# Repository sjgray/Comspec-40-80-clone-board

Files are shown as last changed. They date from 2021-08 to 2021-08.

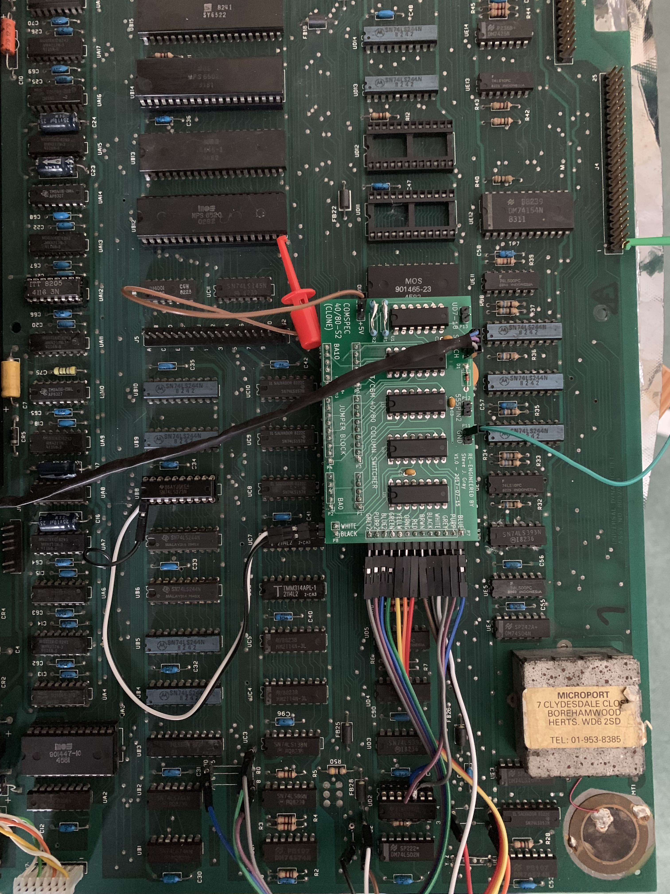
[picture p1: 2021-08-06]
pics/IMG_3752.jpg

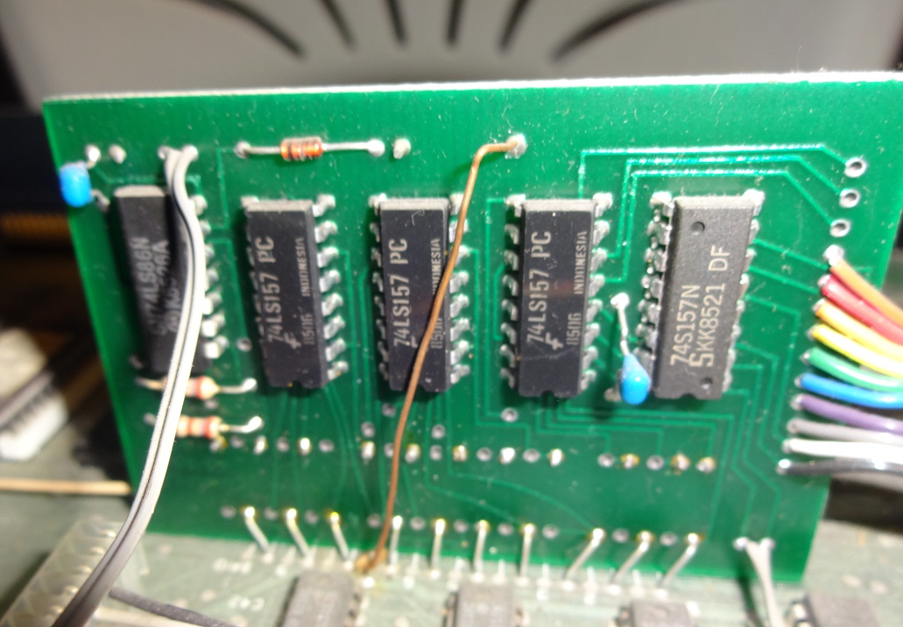
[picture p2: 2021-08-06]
pics/Comspec4080s2.jpg

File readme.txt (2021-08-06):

Comspec 40/80-S2 board Clone
============================

This is a clone of the Comspec 40/80 S2 board for PET/CBM computers.
This board allows the PET to switch between real 40 or 80 column video modes.
Whe the board is switched the computer is reset. These boards were supplied
with both 40 and 80 column Editor ROMs combined into a single EPROM. A wire
from the Comspec board to the upper address pin of the EPROM automatically
selected the correct ROM for the selected video mode.

More information can be found on the web:
http://www.6502.org/users/sjgray/projects/cbm4080/index.html

Steve

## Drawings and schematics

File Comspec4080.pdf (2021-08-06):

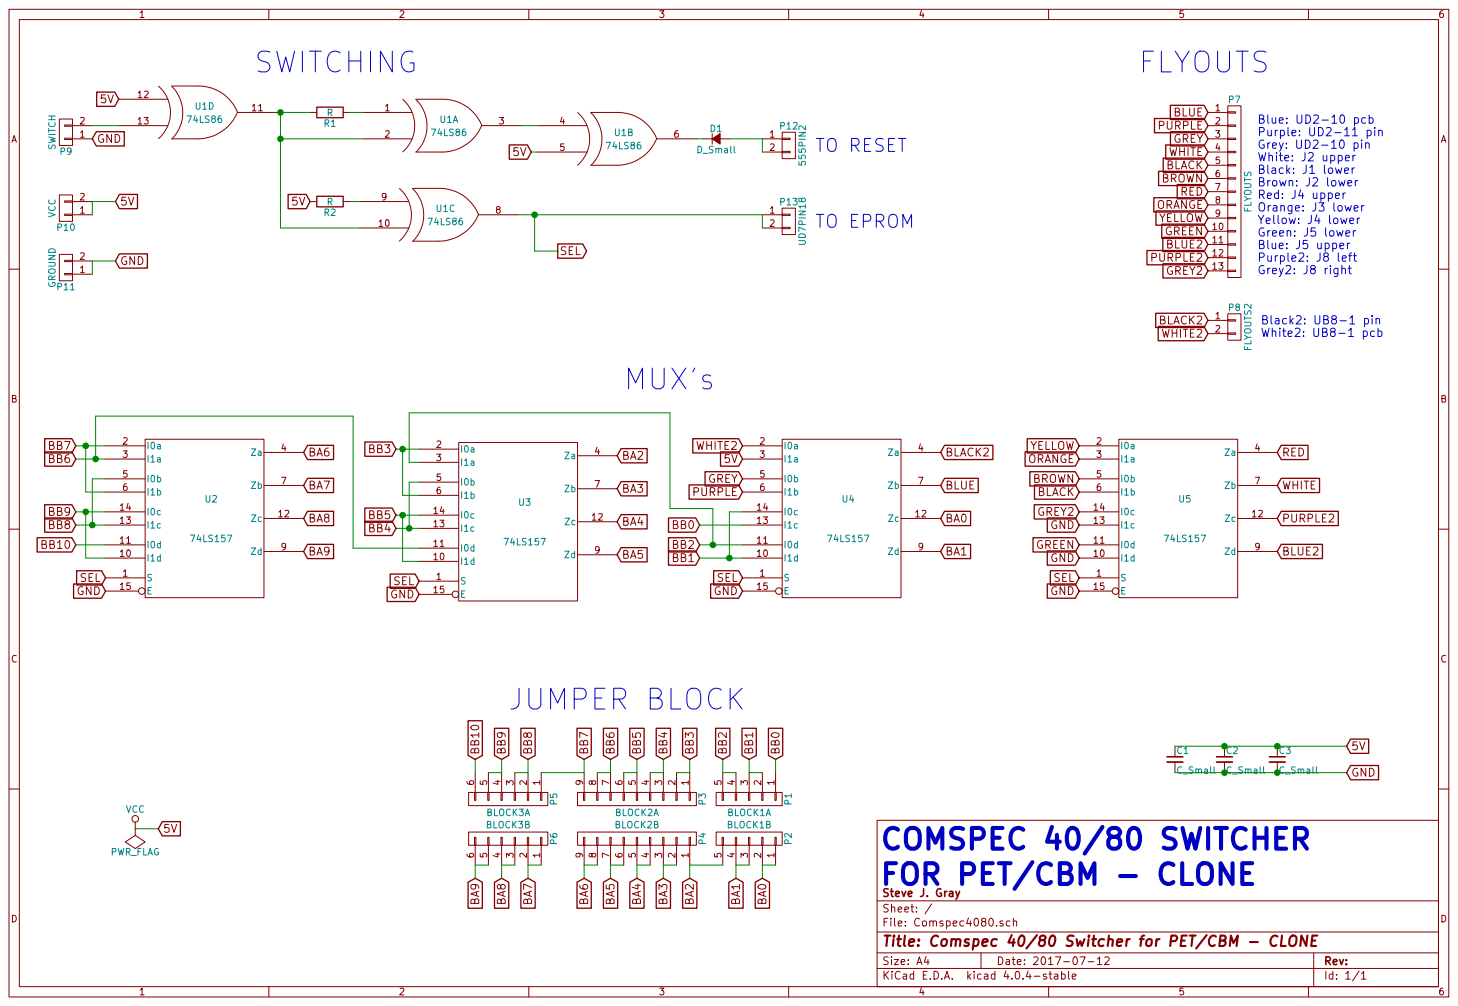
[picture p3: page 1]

FOR PET/CBM - CLONE

Id: 1/1 Title: Comspec 40/80 Switcher for PET/CBM - CLONE

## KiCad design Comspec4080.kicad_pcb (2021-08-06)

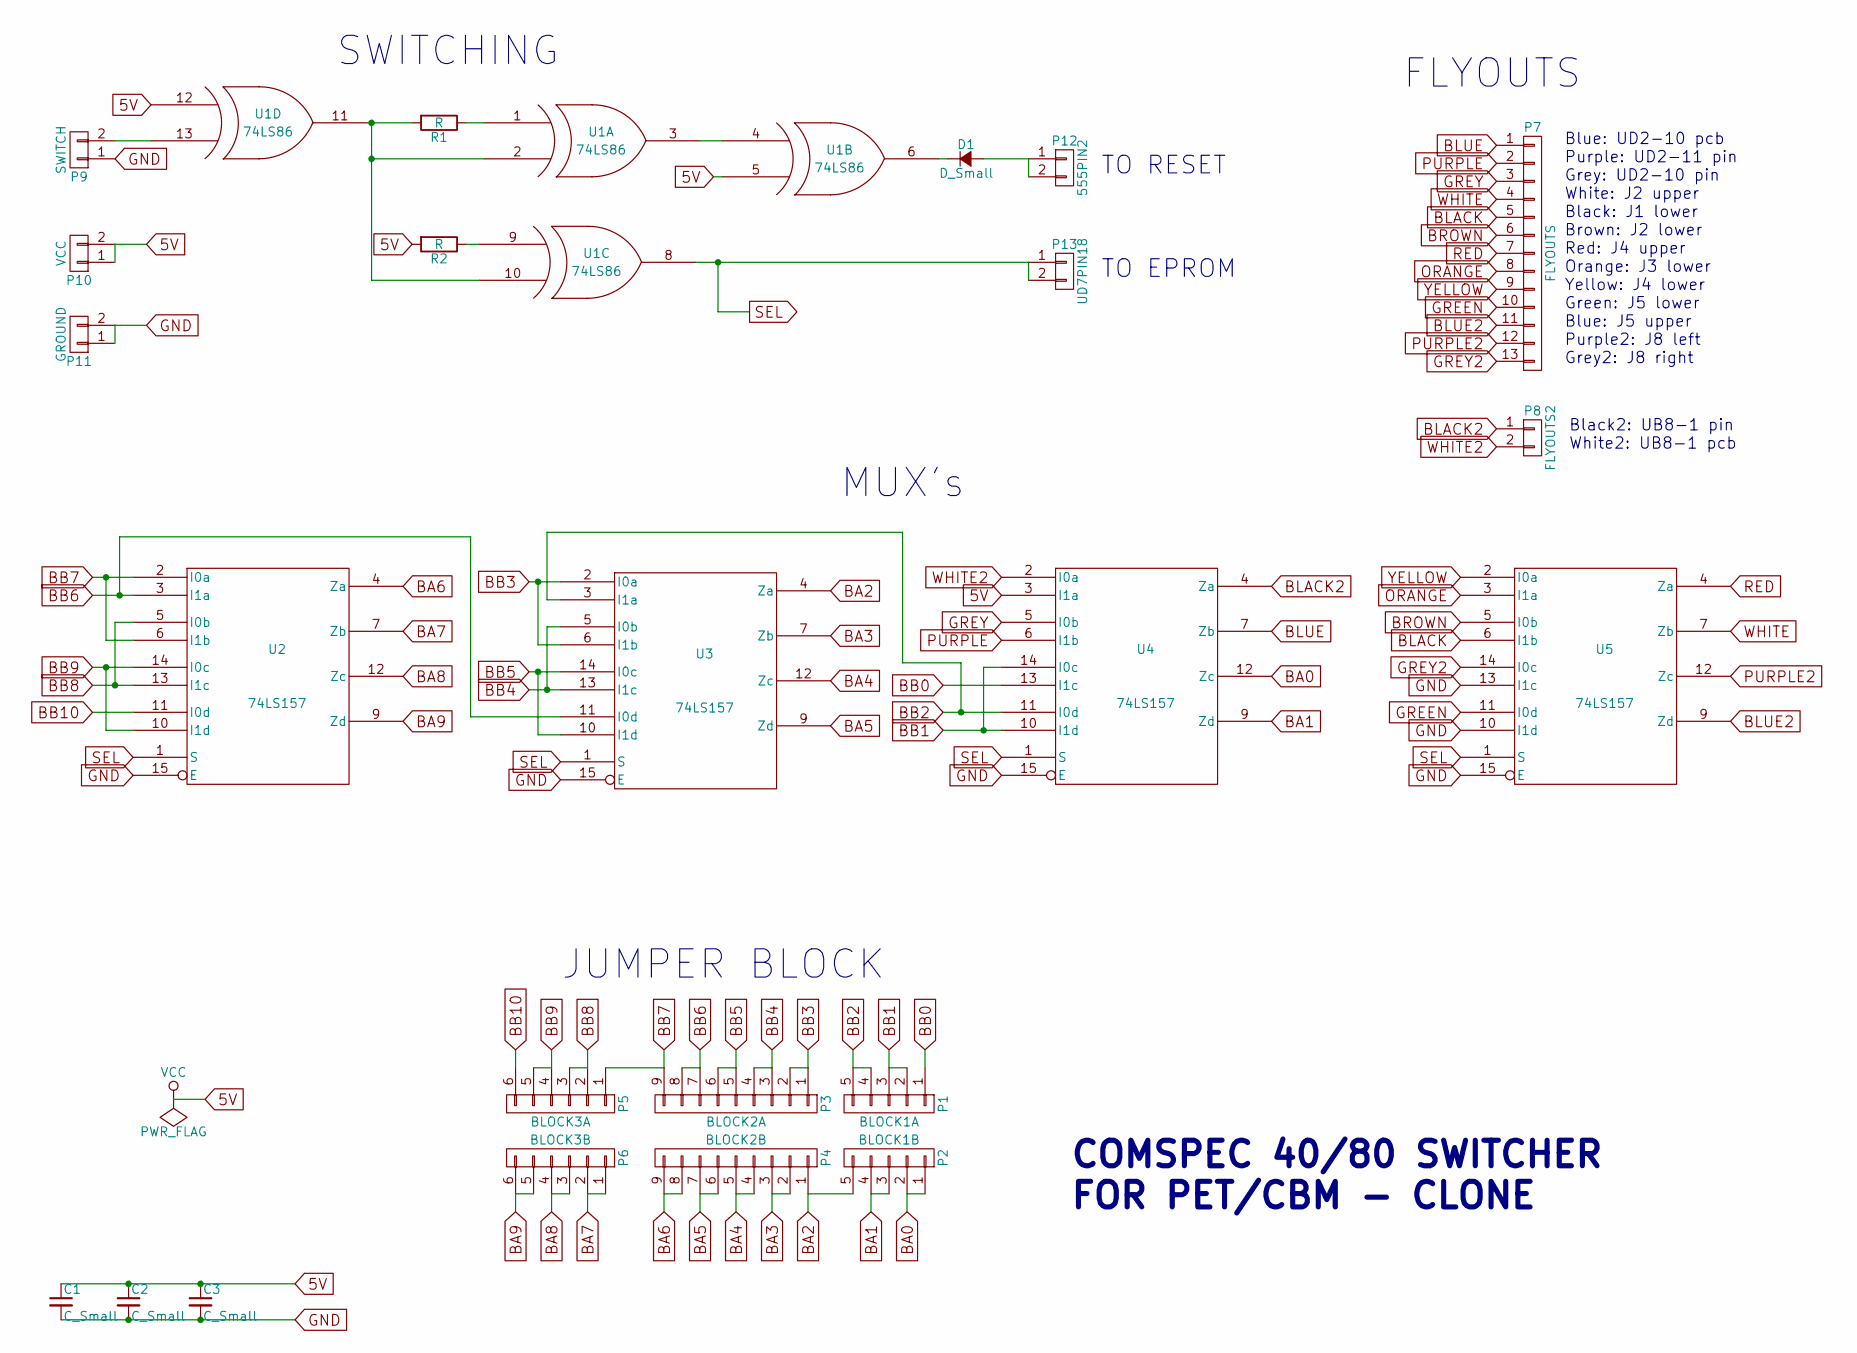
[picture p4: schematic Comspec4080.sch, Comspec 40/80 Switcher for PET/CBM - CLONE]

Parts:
C1, C2, C3: C_Small; C_Disc_D3.0mm_W1.6mm_P2.50mm
D1: D_Small; D_A-405_P7.62mm_Horizontal
P1: BLOCK1A; Pin_Header_Straight_1x05_Pitch2.54mm
P2: BLOCK1B; Pin_Header_Straight_1x05_Pitch2.54mm
P3: BLOCK2A; Pin_Header_Straight_1x09_Pitch2.54mm
P4: BLOCK2B; Pin_Header_Straight_1x09_Pitch2.54mm
P5: BLOCK3A; Pin_Header_Straight_1x06_Pitch2.54mm
P6: BLOCK3B; Pin_Header_Straight_1x06_Pitch2.54mm
P7: FLYOUTS; Pin_Header_Straight_1x13_Pitch2.54mm
P8: FLYOUTS2; Pin_Header_Straight_1x02_Pitch2.54mm
P9: SWITCH; Pin_Header_Straight_1x02_Pitch2.54mm
P10: VCC; Pin_Header_Straight_1x02_Pitch2.54mm
P11: GROUND; Pin_Header_Straight_1x02_Pitch2.54mm
P12: 555PIN2; Pin_Header_Straight_1x02_Pitch2.54mm
P13: UD7PIN18; Pin_Header_Straight_1x02_Pitch2.54mm
R1, R2: R; R_Axial_DIN0207_L6.3mm_D2.5mm_P7.62mm_Horizontal
U1: 74LS86; DIP-14_W7.62mm_LongPads
U2, U3, U4, U5: 74LS157; DIP-16_W7.62mm_LongPads

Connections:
5V: C1.1, C2.1, C3.1, P10.1, P10.2, R2.2, U1.5 (IN2), U1.12 (IN1), U1.14 (VCC), U2.16 (VCC), U3.16 (VCC), U4.3 (I1a), U4.16 (VCC), U5.16 (VCC)
BA0: P2.1, P2.2, U4.12 (Zc)
BA1: P2.3, P2.4, U4.9 (Zd)
BA2: P2.5, P4.1, U3.4 (Za)
BA3: P4.2, P4.3, U3.7 (Zb)
BA4: P4.4, P4.5, U3.12 (Zc)
BA5: P4.6, P4.7, U3.9 (Zd)
BA6: P4.8, P4.9, U2.4 (Za)
BA7: P6.1, P6.2, U2.7 (Zb)
BA8: P6.3, P6.4, U2.12 (Zc)
BA9: P6.5, P6.6, U2.9 (Zd)
BB0: P1.1, U4.13 (I1c)
BB1: P1.2, P1.3, U4.10 (I1d), U4.14 (I0c)
BB2: P1.4, P1.5, U3.3 (I1a), U4.11 (I0d)
BB3: P3.1, P3.2, U3.2 (I0a), U3.6 (I1b)
BB4: P3.3, P3.4, U3.5 (I0b), U3.13 (I1c)
BB5: P3.5, P3.6, U3.10 (I1d), U3.14 (I0c)
BB6: P3.7, P3.8, U2.3 (I1a), U3.11 (I0d)
BB7: P3.9, P5.1, U2.2 (I0a), U2.6 (I1b)
BB8: P5.2, P5.3, U2.5 (I0b), U2.13 (I1c)
BB9: P5.4, P5.5, U2.10 (I1d), U2.14 (I0c)
BB10: P5.6, U2.11 (I0d)
BLACK: P7.5, U5.6 (I1b)
BLACK2: P8.1, U4.4 (Za)
BLUE: P7.1, U4.7 (Zb)
BLUE2: P7.11, U5.9 (Zd)
BROWN: P7.6, U5.5 (I0b)
GND: C1.2, C2.2, C3.2, P9.1, P11.1, P11.2, U1.7 (GND), U2.8 (GND), U2.15 (E), U3.8 (GND), U3.15 (E), U4.8 (GND), U4.15 (E), U5.8 (GND), U5.10 (I1d), U5.13 (I1c), U5.15 (E)
GREEN: P7.10, U5.11 (I0d)
GREY: P7.3, U4.5 (I0b)
GREY2: P7.13, U5.14 (I0c)
unnamed: D1.1 (K), U1.6 (OUT)
unnamed: D1.2 (A), P12.1, P12.2
unnamed: P9.2, U1.13 (IN2)
unnamed: R1.1, U1.1 (IN1)
unnamed: R1.2, U1.2 (IN2), U1.10 (IN2), U1.11 (OUT)
unnamed: R2.1, U1.9 (IN1)
unnamed: U1.3 (OUT), U1.4 (IN1)
ORANGE: P7.8, U5.3 (I1a)
PURPLE: P7.2, U4.6 (I1b)
PURPLE2: P7.12, U5.12 (Zc)
RED: P7.7, U5.4 (Za)
SEL: P13.1, P13.2, U1.8 (OUT), U2.1 (S), U3.1 (S), U4.1 (S), U5.1 (S)
WHITE: P7.4, U5.7 (Zb)
WHITE2: P8.2, U4.2 (I0a)
YELLOW: P7.9, U5.2 (I0a)

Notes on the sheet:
COMSPEC 40/80 SWITCHER FOR PET/CBM - CLONE
SWITCHING
FLYOUTS
TO EPROM
TO RESET
JUMPER BLOCK
MUX's
Blue: UD2-10 pcb Purple: UD2-11 pin Grey: UD2-10 pin White: J2 upper Black: J1 lower Brown: J2 lower Red: J4 upper Orange: J3 lower Yellow: J4 lower Green: J5 lower Blue: J5 upper Purple2: J8 left Grey2: J8 right
Black2: UB8-1 pin White2: UB8-1 pcb

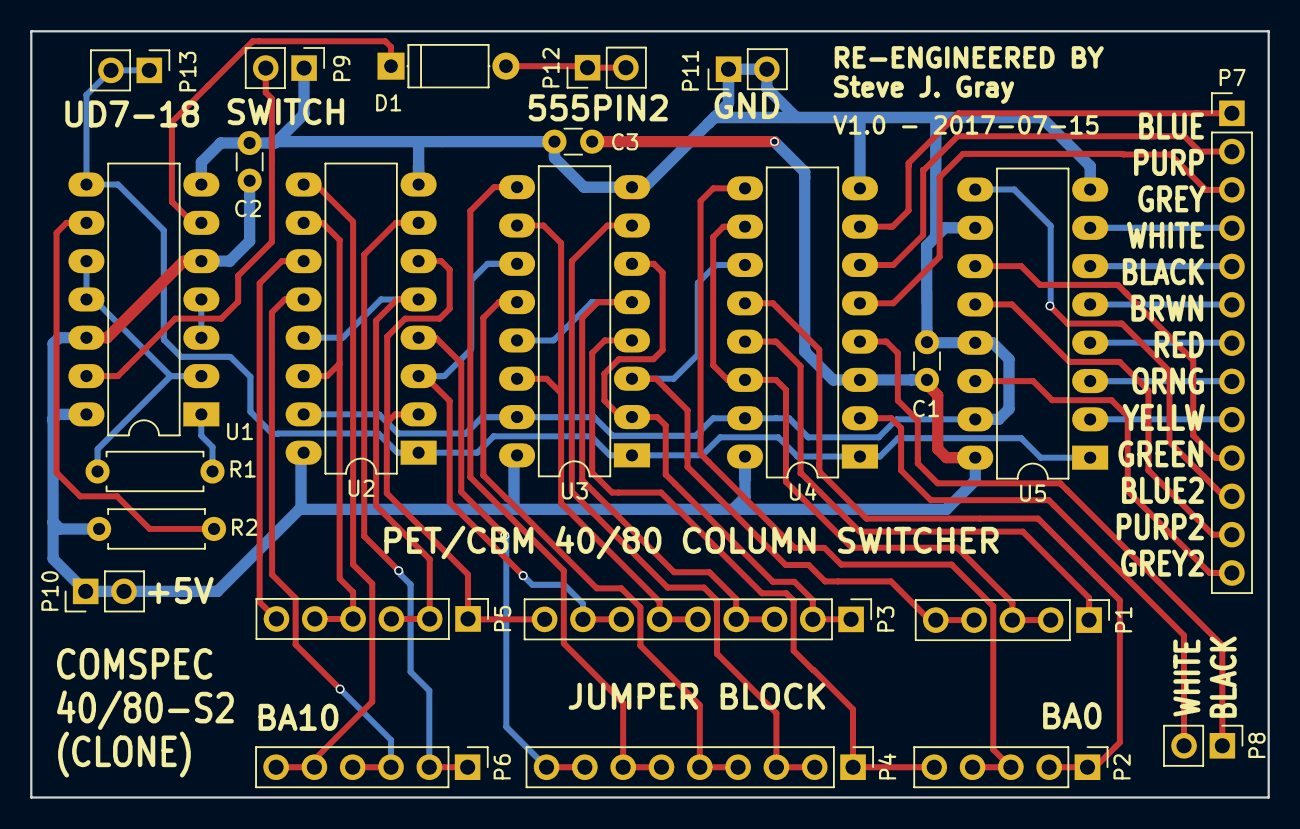
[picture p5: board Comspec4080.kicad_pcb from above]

Board: 2 copper layers, 82.0 x 50.8 mm, 24 parts (0 on the bottom side), 46 nets.
